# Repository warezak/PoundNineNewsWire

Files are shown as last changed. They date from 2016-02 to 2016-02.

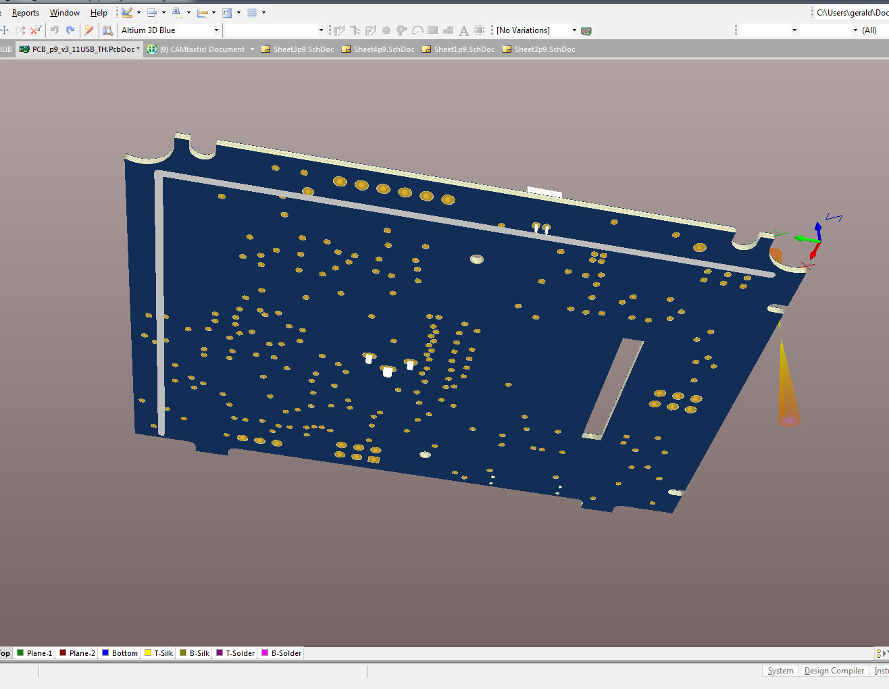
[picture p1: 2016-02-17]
PCB/pcb_p9_v3_view4.jpg

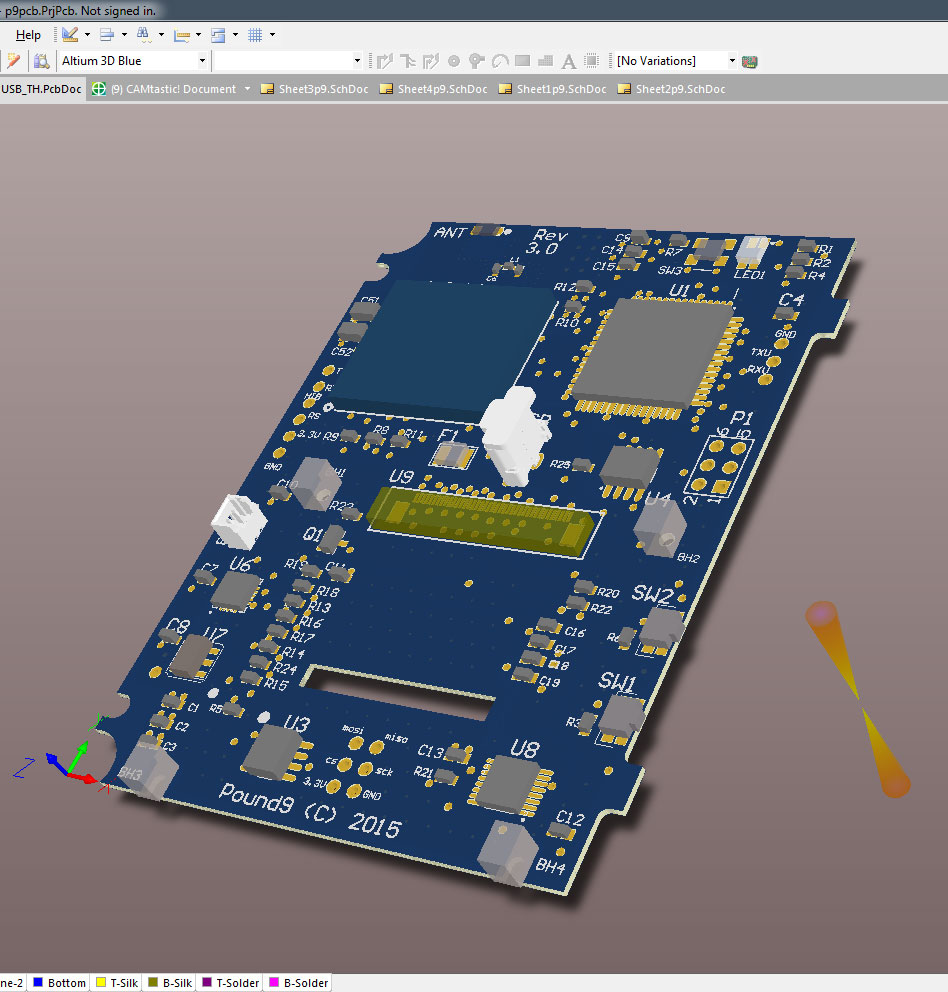
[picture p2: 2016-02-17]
PCB/pcb_p9_v3_view2.jpg

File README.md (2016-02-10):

# PoundNineNewsWire
Source code for #9 Personal News Wire

The Pound Nine Wire is a wifi enabled (TICC3100), battery operated, hardware device with 3.2" touch screen display. The Pound Nine Wire continually streams live headlines from a database of content. Just glance at the device to stay informed while you stay focused on the tasks at hand.

A full description of the product can be view on the project kickstarter page: https://www.kickstarter.com/projects/1547604553/stream-live-news-updates-on-your-personal-wire

The product was not funded and is not be pursued at this time. A lot of work went into the hardware and firmware design which is posted here. Feel free to leverage the source code in your projects. The project uses a Atmel ATxmega256A3U and TICC3100. Schema and gerber files are available in PCB directory. Firmware to connect device to internet and continually retreive content is posted in Firmware folder. ImageLoader is firmware to load image hex files onto SRAM chip. Not elegant, but functional.

There is a companion android app that operates as a news wire, publishing the same content pushed to the standalone hardware. In the mobile app is a customized version of the CC3100 smart config app. 

The 3d model files are available so you can print your own case.

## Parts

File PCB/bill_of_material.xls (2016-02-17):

Manufacturer | Manufacturer Part Number | Supplier | Supplier Part Number | Required Quantity | Reference Designator (Component Location) | Existing Stock Availablity | Order Quantity | Currency | Mike tmp | Mike Ext | Unit Price | Total Price | MOQ | Residual Quantity | Base Part Number
Taiyo Yuden | AH316M245001-T | Digikey | 587-2200-1-ND | 1 | ANT | 0 | 1 | USD | 0.585 | 0.585 | 1.95 | 1.95 | 1 | 0 | AH316M245001-T
Murata | GJM1555C1H1R0CB01D | Digikey | 490-3083-1-ND | 1 | C6 | 0 | 1 | USD | 0.12 | 0.12 | 0.12 | 0.12 | 1 | 0 | CAP CER 1PF 50V NP0 0402
Vishay / Vitramon | VJ0603Y104JXQPW1BC | Mouser | 77-VJ0603Y104JXQPBC | 9 | C1, C4, C12, C13, C14, C16, C17, C18, C19 | 0 | 9 | USD | 0.1 | 0.9 | 0.1 | 0.5 | 1 | 0 | VJ0603Y104JXQPW1BC
TDK | C1005X5R1C105K050BC | Digikey | 445-4978-1-ND | 3 | C11,C2,C15 | 0 | 3 | USD | 0.016 | 0.048 | 0.12 | 0.36 | 1 | 0 | X5R-1u-16V-20%-0603
AVX | F930J107KAA | Digikey | 478-8152-1-ND | 2 | C51,C52 | 0 | 2 | USD | 0.85 | 1.7 | 0.89 | 1.78 | 1 | 0 | F930J107KAA
Molex | 530470210 | Mouser | 538-53047-0210 | 1 | P3 | 0 | 1 | USD | 0.11587 | 0.11587 | 0.35 | 0.35 | 1 | 0 | 530470210
Molex | 105133-0011 | Mouser | 538-105133-0011 | 1 | P2 | 0 | 1 | USD | 1.06 | 1.06 | 1.11 | 1.11 | 1 | 0 | 105133-0011
BUYDISPLAY | ER-CON40HT-1 | BUYDISPLAY | ER-CON40HT-1 | 1 | U9 | 0 | 1 | USD | 0.17 | 0.17 | 0.17 | 0.17 | 1 | 0 | ER-CON40HT-1
Bourns | MF-USMF110-2 | Digikey | MF-USMF110-2CT-ND | 1 | F1 | 0 | 1 | USD | 0.181 | 0.181 | 0.29 | 0.29 | 1 | 0 | MF-USMF110-2
Microchip Technology | 23A256-I/SN | Mouser | 579-23A256-I/SN | 1 | U4 | 0 | 1 | USD | 1.04 | 1.04 | 1.28 | 1.28 | 1 | 0 | 23A256-I/SN
XPT | XPT-2046 | ALIBABA | XPT-2046 | 1 | U8 | 0 | 1 | USD | 0.2 | 0.2 | 0.2 | 0.2 | 1 | 0 | XPT-2046
Adesto Technologies | AT45DB161E-SSHF-B | Digikey | 1265-1058-ND | 1 | U3 | 0 | 1 | USD | 1.87 | 1.87 | 2.15 | 2.15 | 1 | 0 | AT45DB161E-SSHF-B
Atmel | ATXMEGA256A3U-AU | Digikey | ATXMEGA256A3U-AU-ND | 1 | U1 | 0 | 1 | USD | 6.169 | 6.169 | 7.26 | 7.26 | 1 | 0 | ATXMEGA256A3U-AU
TI (Texas Instruments) | CC3100MODR11MAMOB | Mouser | 595-3100MODR11MAMOBR | 1 | CC3100M | 0 | 1 | USD | 21.95 | 21.95 | 21.95 | 21.95 | 1 | 0 | CC3100MODR11MAMOB
Microchip Technology | MCP73871-2CCI/ML | Digikey | MCP73871-2CCI/ML-ND | 1 | U6 | 0 | 1 | USD | 1.67 | 1.67 | 1.79 | 1.79 | 1 | 0 | MCP73871-2CCI/ML
On Semiconductor | NCP694D33HT1G | Digikey | NCP694D33HT1GOSCT-ND | 1 | U7 | 0 | 1 | USD | 1.52 | 1.52 | 1.52 | 1.52 | 1 | 0 | NCP694D33HT1G
Taiyo Yuden | HK10053N6S-T | Digikey | 587-1508-1-ND | 1 | L1 | 0 | 1 | USD | 0.012 | 0.012 | 0.1 | 0.1 | 1 | 0 | FIXED IND 3.6NH 500MA 0402
Visual Communications Company (VCC) | VAOL-S1513RGB | Mouser | 593-VAOL-S1513RGB | 1 | LED1 | 0 | 1 | USD | 0.663 | 0.663 | 1.69 | 1.69 | 1 | 0 | VAOL-S1513RGB
Yageo | RC0603FR-071M5L | Digikey | 311-1.50MHRCT-ND | 1 | R18 | 0 | 1 | USD | 0.048 | 0.048 | 0.09 | 0.09 | 1 | 0 | 1.5M--100mW-1%-0603
Yageo | RC0603FR-07100KL | Mouser | 603-RC0603FR-07100KL | 2 | R11,R16 | 0 | 2 | USD | 0.002 | 0.004 | 0.1 | 0.2 | 1 | 0 | 100K-63mW-5%-0603
Yageo | RC0603FR-0710KL | Mouser | 603-RC0603FR-0710KL | 15 | R3, R5, R6, R7, R8, R9, R10, R12, R13, R14, R15, R20, R22, R24, R25 | 0 | 15 | USD | 0.002 | 0.03 | 0.01 | 0.15 | 1 | 0 | 10K-63mW-5%-0603
Yageo | RC0603FR-071KL | Mouser | 603-RC0603FR-071KL | 3 | R1, R2, R4 | 0 | 3 | USD | 0.002 | 0.006 | 0.1 | 0.3 | 1 | 0 | 1K-63mW-5%-0603
Yageo | RC0603FR-072K49L | Digikey | 311-2.49KHRCT-ND | 2 | R17,R23 | 0 | 2 | USD | 0.002 | 0.004 | 0.1 | 0.2 | 1 | 0 | 2.49K-100mW-1%-0603
Yageo | RC0603FR-07430KL | Digikey | 311-430KHRCT-ND | 1 | R19 | 0 | 1 | USD | 0.1 | 0.1 | 0.1 | 0.1 | 1 | 0 | 430K-100mW-1%-0603
Yageo | RC0603FR-0749K9L | Digikey | 311-49.9KHRCT-ND | 1 | R21 | 0 | 1 | USD | 0.038 | 0.038 | 0.1 | 0.1 | 1 | 0 | 49.9K-100mW-1%-0603
ITT / C&K Components | KMT021NGJLHS | Mouser | 611-KMT021NGJLHS | 1 | SW3 | 0 | 1 | USD | 0.155 | 0.155 | 0.43 | 0.43 | 1 | 0 | KMT021NGJLHS
ITT / C&K Components | PTS840GKPSMTRLFS | Mouser | 611-PTS840GKPSMTR | 2 | SW1,SW2 | 0 | 2 | USD | 0.32 | 0.64 | 0.32 | 0.64 | 1 | 0 | PTS840GKPSMTRLFS
On Semiconductor | MMBT3906LT1G | Digikey | MMBT3906LT1GOSCT-ND | 1 | Q1 | 0 | 1 | USD | 0.031 | 0.031 | 0.11 | 0.11 | 1 | 0 | MMBT3906LT1G
Murata | GRM188R61A106KE69D | Mouser | 81-GRM188R61A106KE9D | 5 | C3,C7,C8,C9,C10 | 0 | 5 | USD |  |  | 0.067 | 0.067
BuyDisplay | ER-TFT032-3.1 + Touch | BuyDisplay | ER-TFT032-3.1 + Touch | 1 |  |  |  |  |  |  |  | 9.32 |  |  | ER-TFT032-3.1 + Touch
Battery | 3.7V T5.8*W39*43mm 800mAh 3.7V lipo | Battery | 3.7V T5.8*W39*43mm 800mAh 3.7V lipo | 1 |  |  |  |  |  |  |  | 1.65

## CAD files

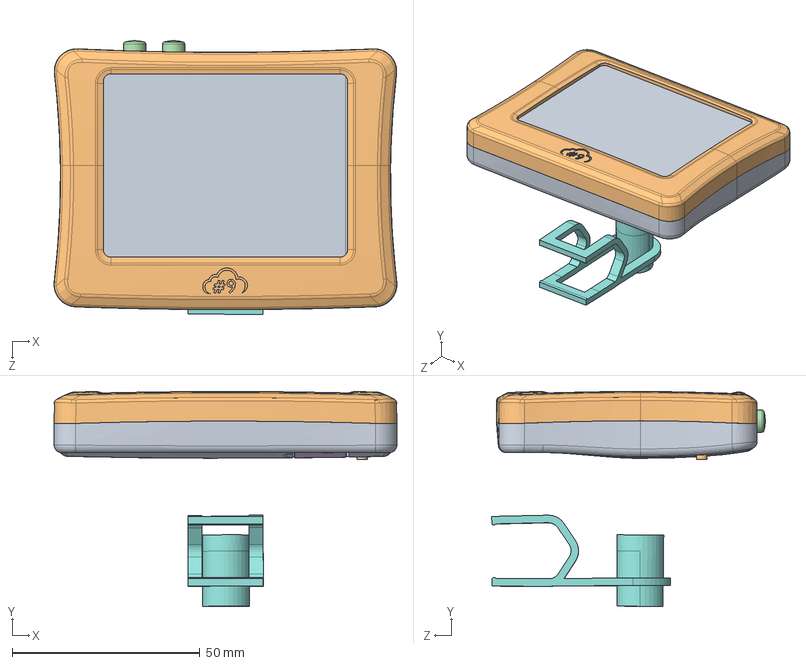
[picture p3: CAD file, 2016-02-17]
3DModel/Solidworks files/Model-221-08-2015.SLDASM
91.3 x 57.3 x 72.8 mm
display21-08-2015
BIVAR LIGHTPIPE PLP2-12521-08-2015
micro-usb21-08-2015
b3u-3100p-b21-08-2015 x 2
Copy of Copy of Wifi-chip^Electronics21-08-2015
3 COLOR LED21-08-2015
Battery-holder21-08-2015
Back21-08-2015
Front-part
battery21-08-2015
Push-button x 2
93365A11021-08-2015 x 4
Kickstand-121-08-2015
pan cross head_ai x 4
91585A01421-08-2015

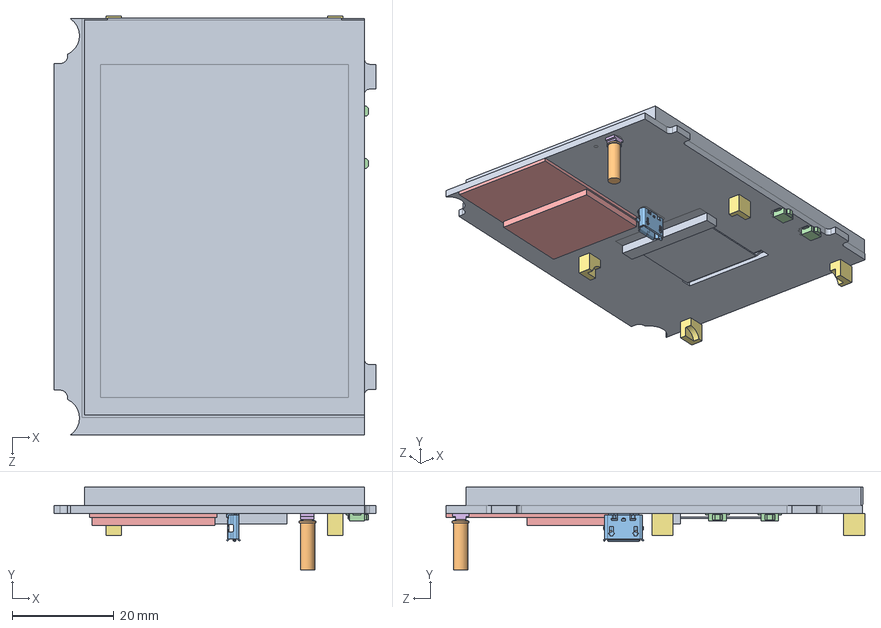
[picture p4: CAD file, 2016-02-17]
3DModel/Solidworks files/Electronics21-08-2015.sldasm
63.2 x 16.3 x 82.3 mm
display21-08-2015
BIVAR LIGHTPIPE PLP2-12521-08-2015
micro-usb21-08-2015
b3u-3100p-b21-08-2015 x 2
Copy of Copy of Wifi-chip^Electronics21-08-2015
3 COLOR LED21-08-2015
Battery-holder21-08-2015

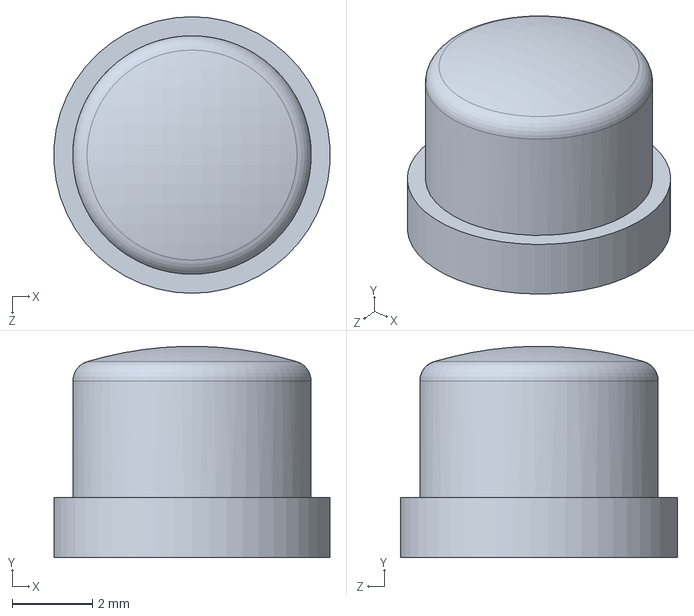
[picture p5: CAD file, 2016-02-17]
3DModel/Solidworks files/Push-button.sldprt
6.89 x 5.27 x 6.90 mm

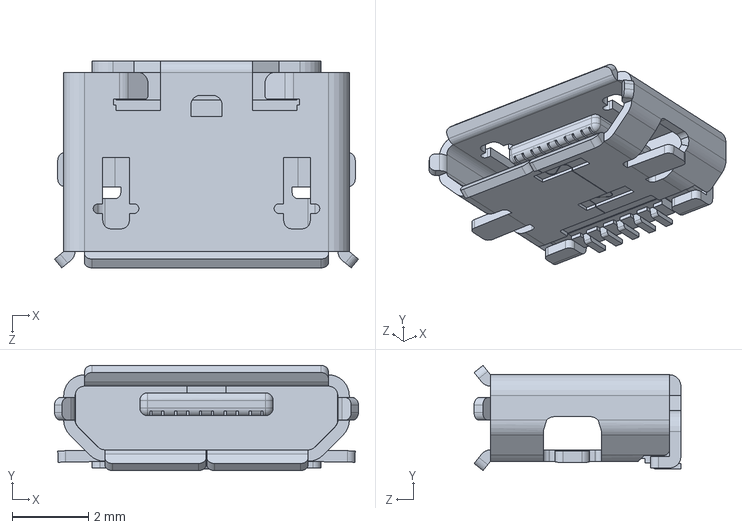
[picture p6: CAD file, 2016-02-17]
3DModel/Solidworks files/micro-usb21-08-2015.SLDPRT
7.98 x 2.76 x 5.43 mm

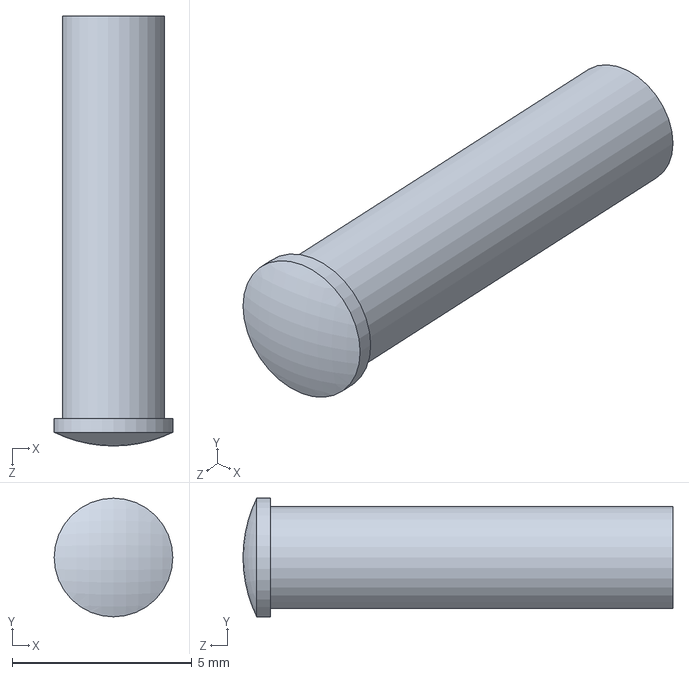
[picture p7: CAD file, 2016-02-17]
3DModel/Solidworks files/BIVAR LIGHTPIPE PLP2-12521-08-2015.sldprt
3.30 x 3.30 x 12.0 mm

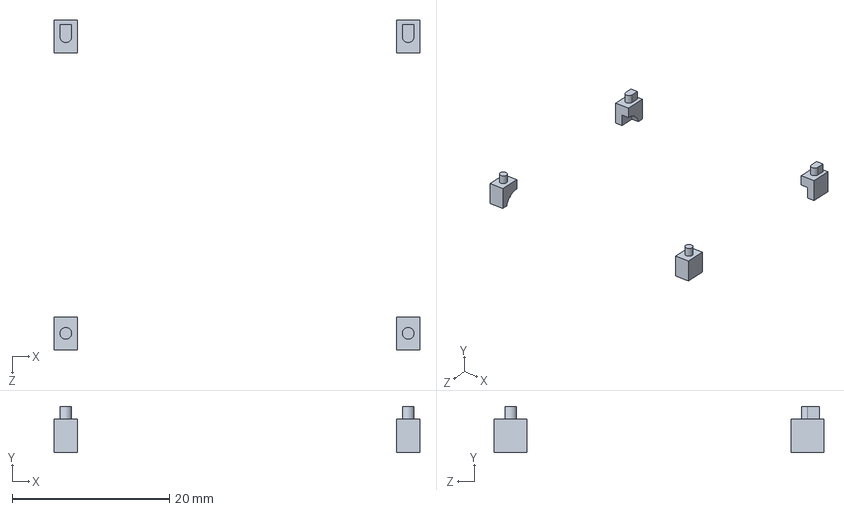
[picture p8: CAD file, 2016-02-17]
3DModel/Solidworks files/Battery-holder21-08-2015.sldprt
46.5 x 5.88 x 41.9 mm

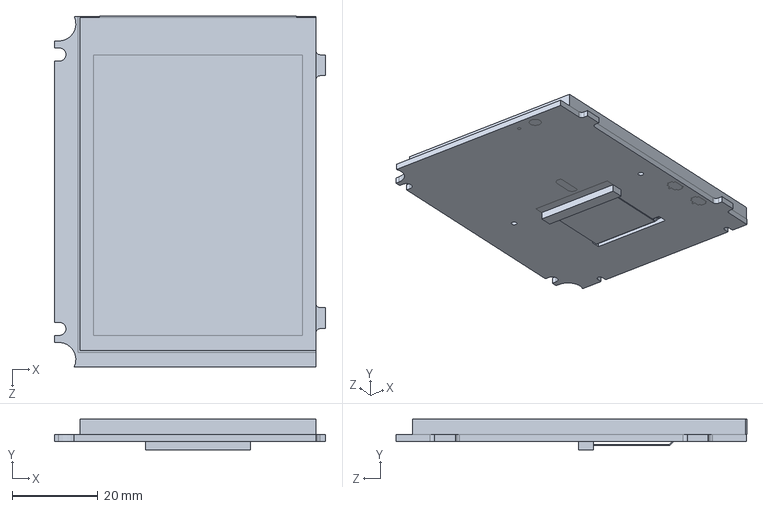
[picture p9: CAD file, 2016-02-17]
3DModel/Solidworks files/display21-08-2015.SLDPRT
63.2 x 7.23 x 81.9 mm

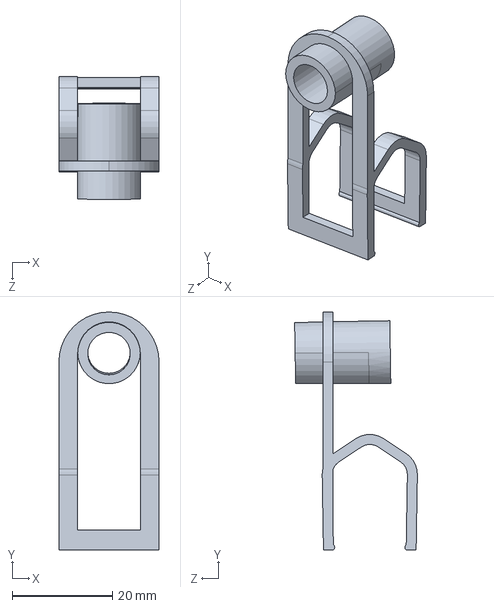
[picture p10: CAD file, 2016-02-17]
3DModel/Solidworks files/Monitor-holder21-08-2015.sldprt
20.0 x 47.5 x 24.5 mm

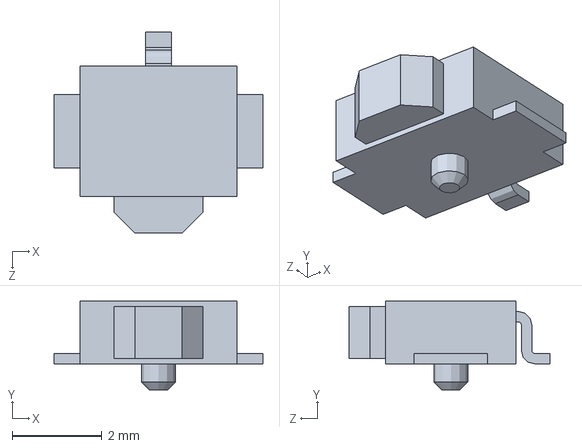
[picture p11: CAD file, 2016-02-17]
3DModel/Solidworks files/b3u-3100p-b21-08-2015.SLDPRT
4.67 x 1.98 x 4.49 mm

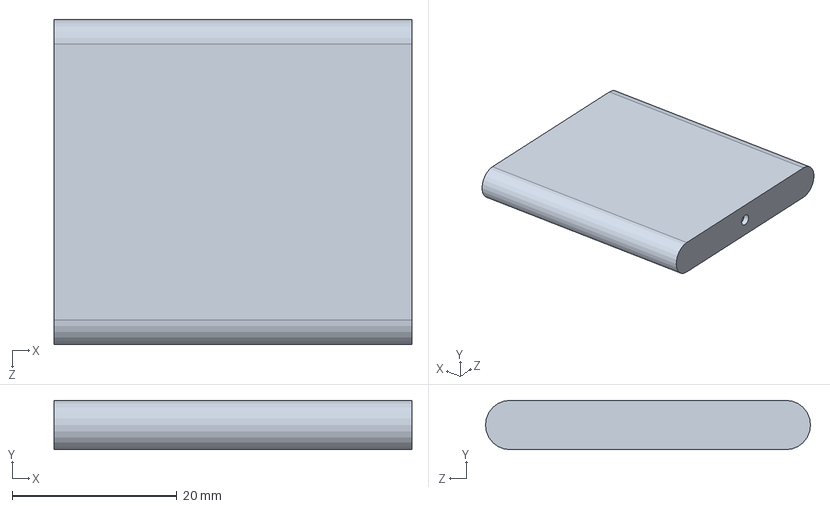
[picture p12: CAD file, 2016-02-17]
3DModel/Solidworks files/battery21-08-2015.SLDPRT
43.5 x 6.00 x 39.5 mm

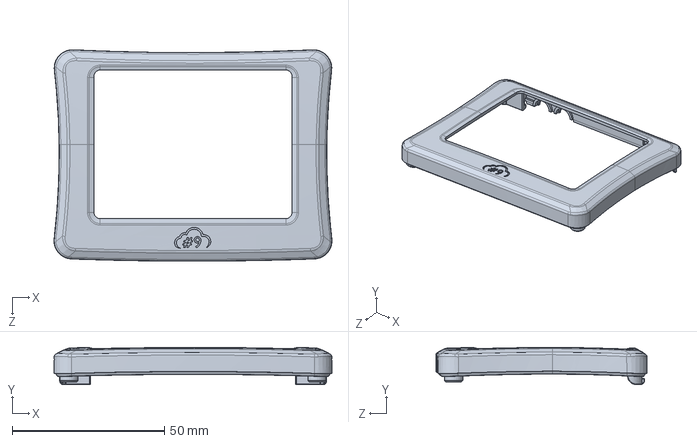
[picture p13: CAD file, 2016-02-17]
3DModel/Solidworks files/Front-part.sldprt
91.3 x 12.2 x 69.4 mm

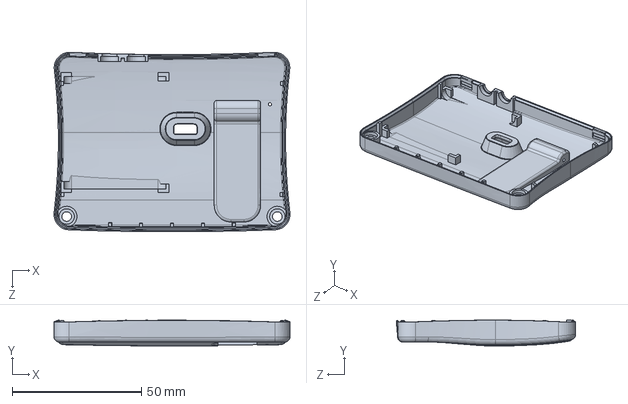
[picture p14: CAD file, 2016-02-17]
3DModel/Solidworks files/Back21-08-2015.sldprt
91.3 x 10.1 x 69.4 mm

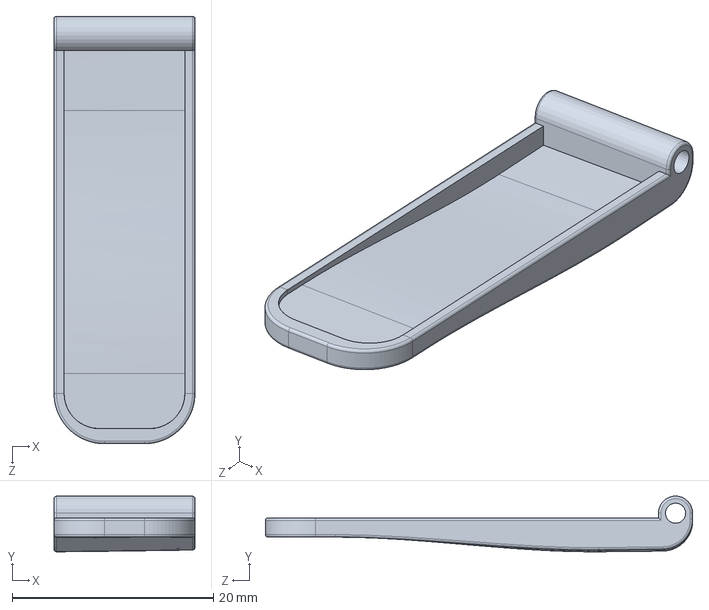
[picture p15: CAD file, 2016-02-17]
3DModel/Solidworks files/Kickstand-121-08-2015.SLDPRT
14.0 x 5.53 x 42.4 mm

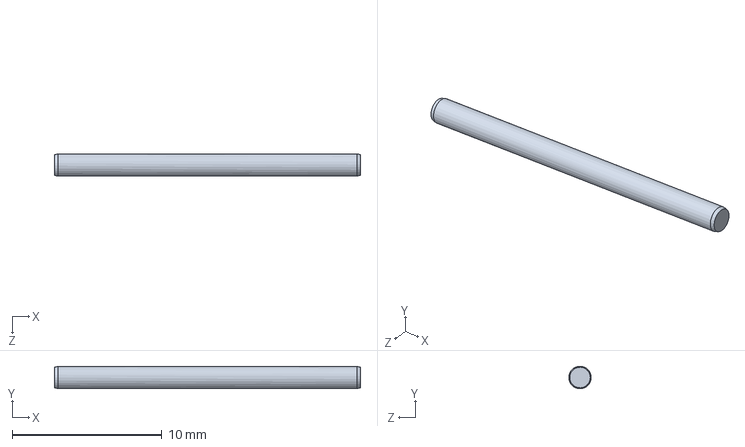
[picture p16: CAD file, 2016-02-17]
3DModel/Solidworks files/91585A01421-08-2015.SLDPRT
20.5 x 1.50 x 1.50 mm

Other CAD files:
3DModel/Solidworks files/3 COLOR LED21-08-2015.sldprt
3DModel/Solidworks files/93365A11021-08-2015.SLDPRT
3DModel/STL files/Push-button.STL

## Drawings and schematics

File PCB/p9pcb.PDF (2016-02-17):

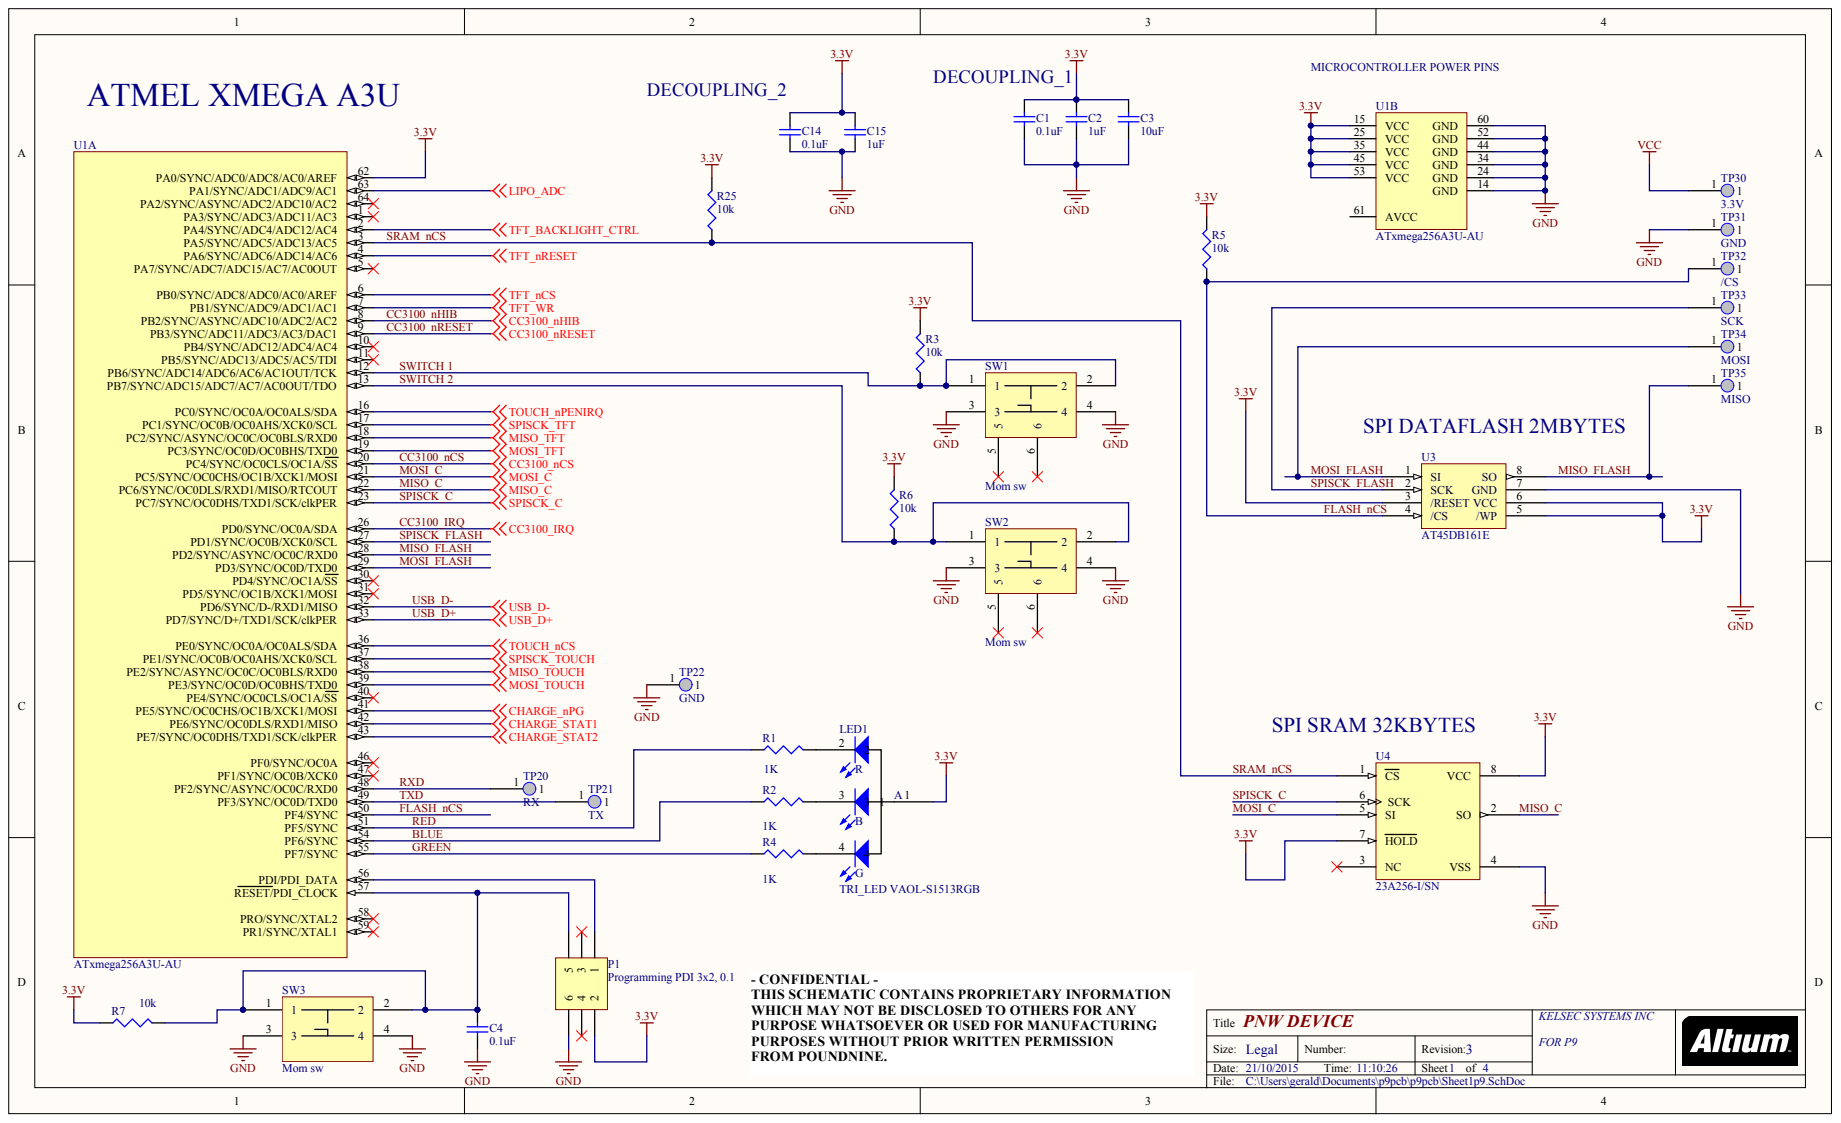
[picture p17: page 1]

2 5 | 5 2
3 5 | 4 4
4 5 | 3 4
5 3 | 2 4

SPISCK_FL

3 | SCK GN D /RESE T VCC /CS /W P | 6

KELSEC SYSTEMS INC FOR P9

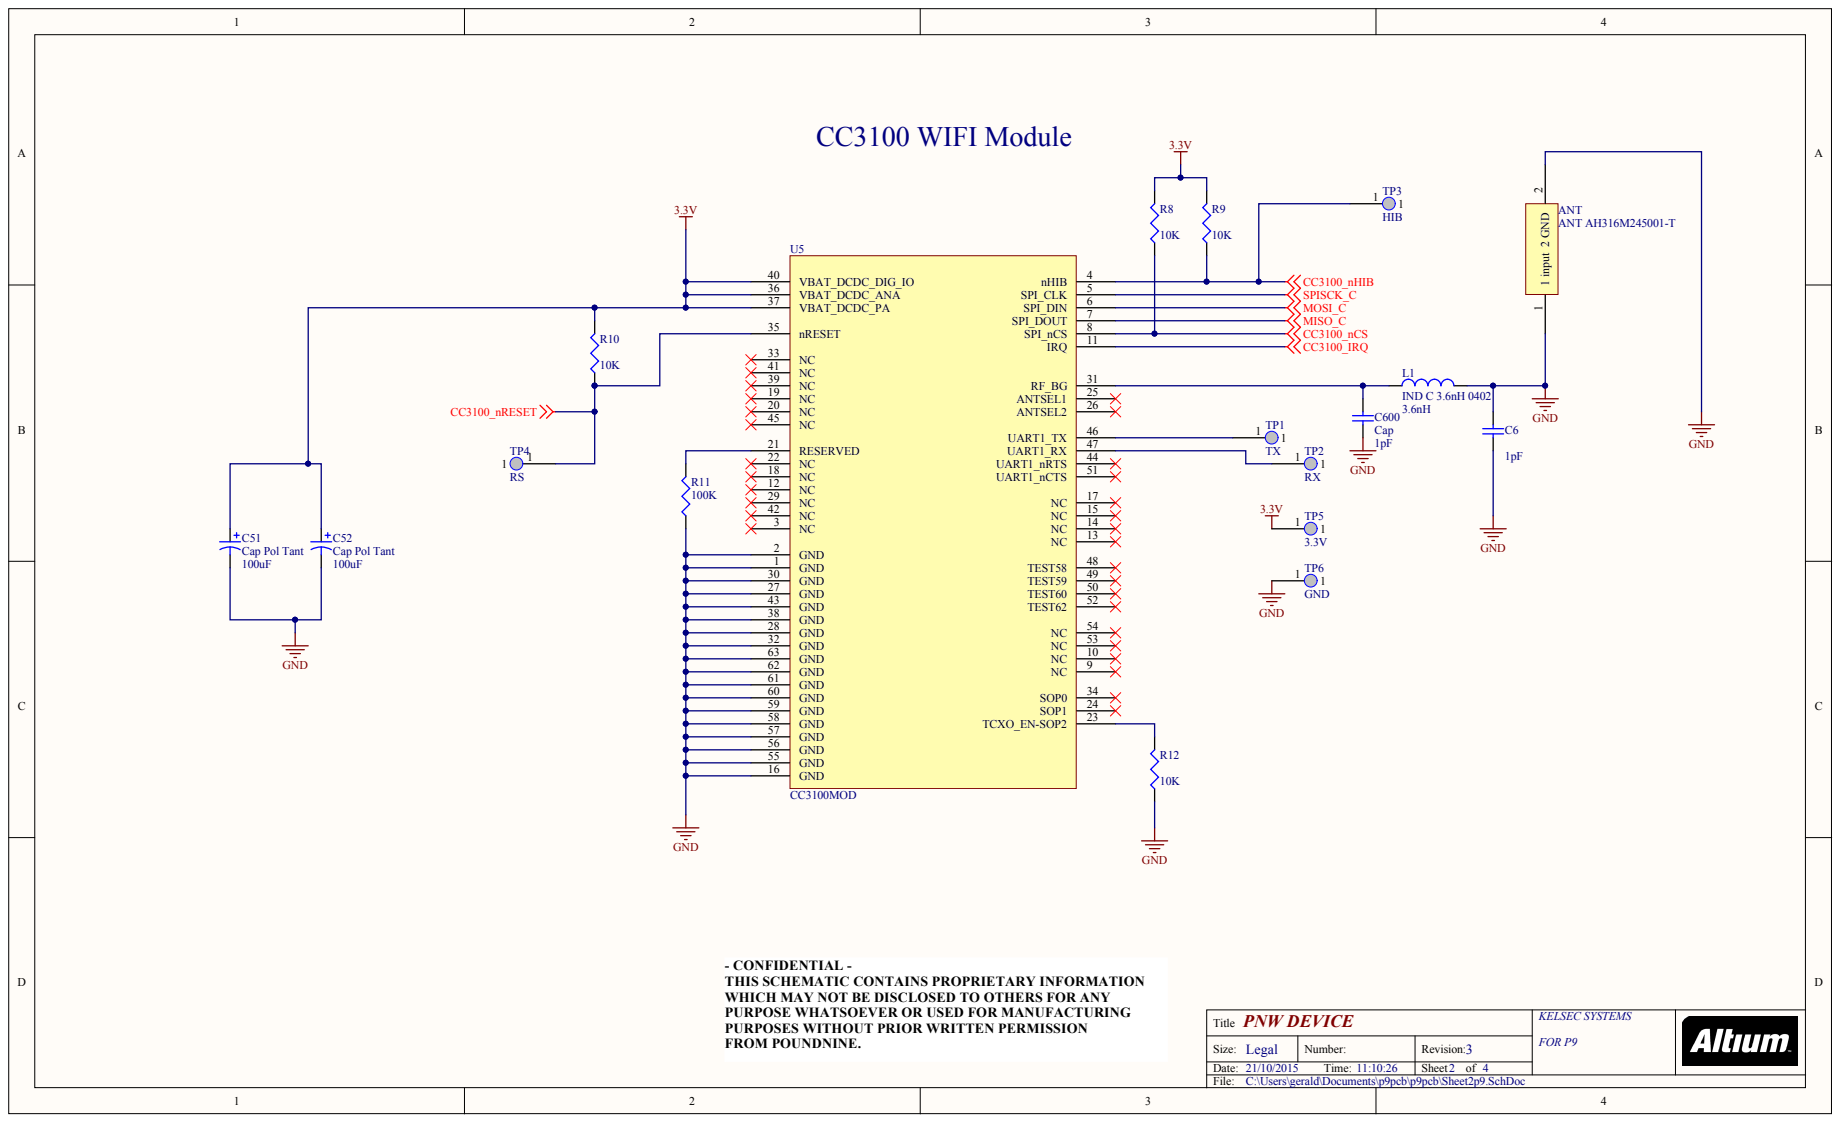
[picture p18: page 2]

3 6
3 7

3 0 | 4 9
2 7 | 5 0
4 3 | 5 2
3 8 | 5 4

3 2 | 5 3
6 3 | 1 0
6 2 | 9
6 1 | 3 4

5 9 | 2 4
5 8 | 2 3

T i t l e PNW DEVICE | KELSEC SYSTEMS FOR P9

Size: Legal | N umber: | Rev i s i o n : 3
Date: 2 1 / 1 0 / 2 0 1 5 T ime: 1 1 : 1 0 : 2 6 | | Sheet 2 o f 4
Fi le: C: \U sers \ geral d\ D ocumen t s \p 9 pcb \p 9 pcb \Sheet 2 p 9.Sch D o c

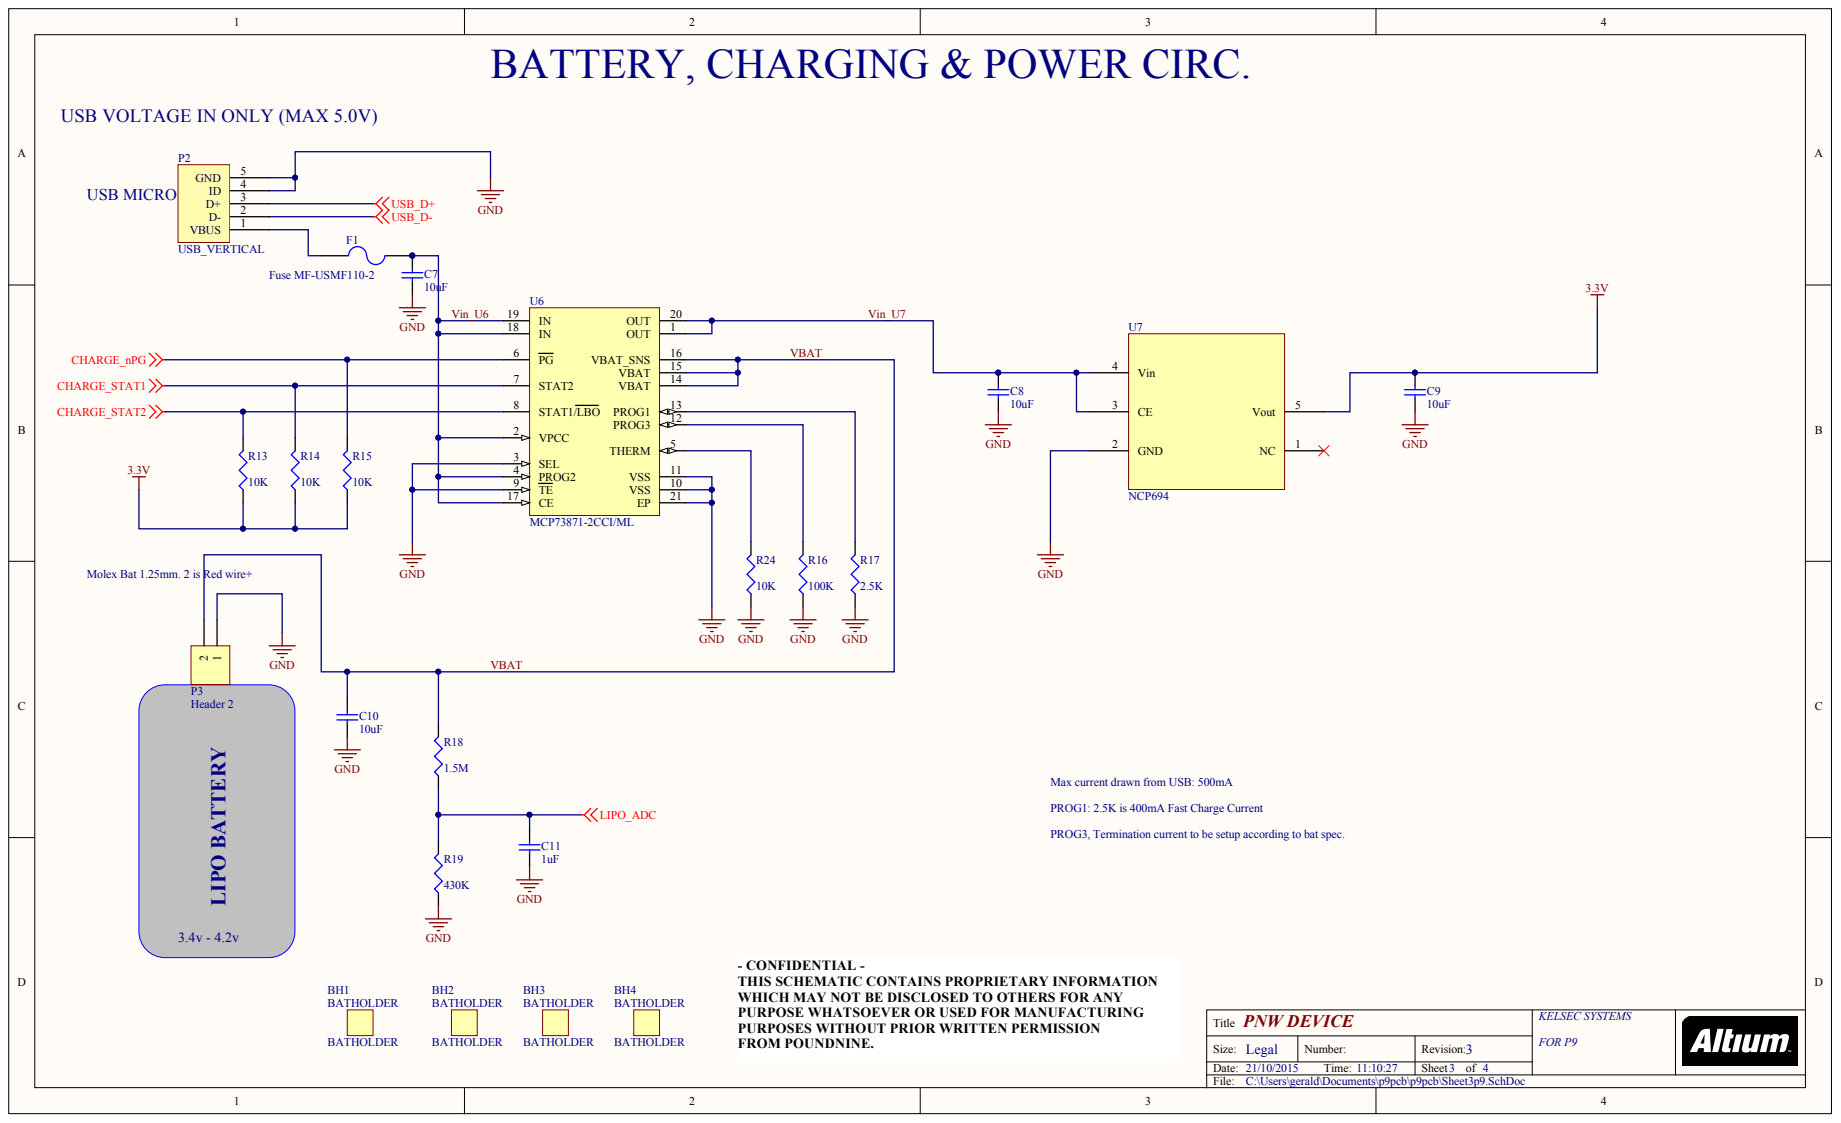
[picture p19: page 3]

BATTERY, CHARGING & POWER CIRC. GND

9 | | 1 0
1 7 | | 2 1

T i t l e PNW DEVICE | KELSEC SYSTEMS FOR P9

Size: Legal | N umber: | Rev i s i o n : 3
Date: 2 1 / 1 0 / 2 0 1 5 T ime: 1 1 : 1 0 : 2 7 | | Sheet 3 o f 4
Fi le: C: \U sers \ geral d\ D ocumen t s \p 9 pcb \p 9 pcb \Sheet 3 p 9.Sch D o c

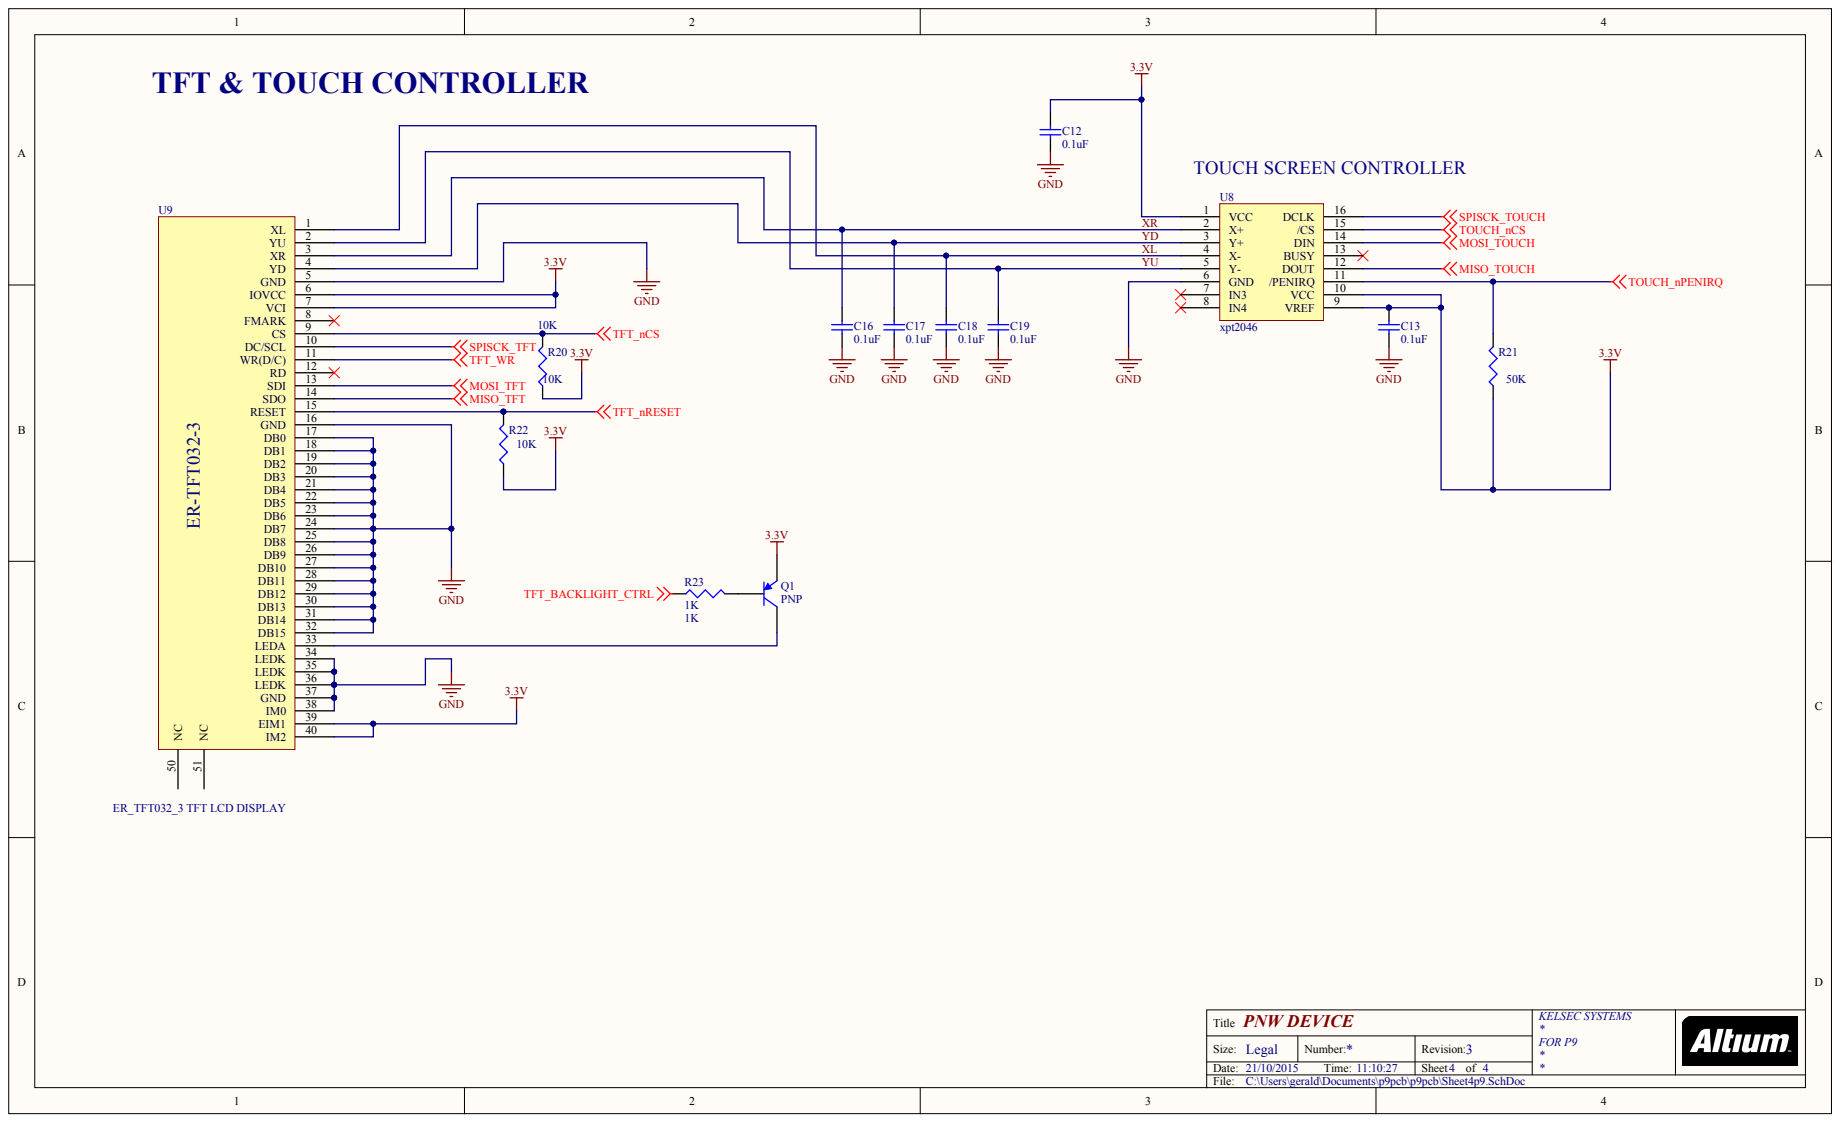
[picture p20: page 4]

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
T i t l e | KELSEC SYSTEMS *FOR P9 * *

Size: Legal | N umber: | Rev i s i o n : 3
Date: 2 1 / 1 0 / 2 0 1 5 T ime: 1 1 : 1 0 : 2 7 | | Sheet 4 o f 4
Fi le: C: \U sers \ geral d\ D ocumen t s \p 9 pcb \p 9 pcb \Sheet 4 p 9.Sch D o c

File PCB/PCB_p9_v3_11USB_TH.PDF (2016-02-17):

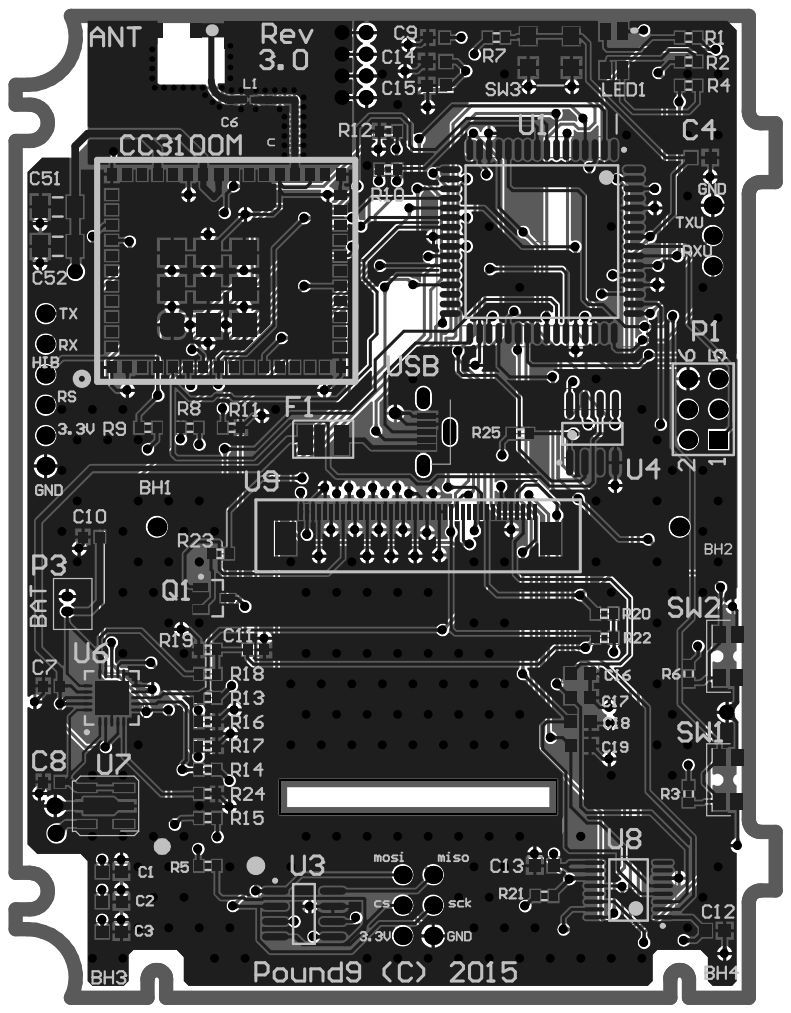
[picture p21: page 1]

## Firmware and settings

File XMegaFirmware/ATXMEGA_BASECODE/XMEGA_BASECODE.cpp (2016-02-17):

/**
 * 
 * XMEGA_BASECODE.cpp
 /*
 */

//Atmel ASF DOES NOT compile under C++ (as of Atmel Studio 6.2) Must use C compiler
extern "C" {
#include "src/asf.h"	
	};
#include <avr/io.h>
#include <util/delay.h>
#include <avr/pgmspace.h>
#include <string.h>

//cc3100 Adafruit for Arduino - modified by gp for atxmega
#include <Adafruit_CC3100.h>
#include "spi_wrapper.h" 
#include <string.h>

#include "cli_uart_wrapper.h" // Debug Only
#include "screens.h" // uses in screen loading
#include "ui_objects.h" // uses in touch test
#include "SRAM23K256.h" //uses for ram
#include "BaseCodeSub.h"

typedef char CHAR; 
//function prototype
//arduino compatibility
void setup();
void loop();
void wifi_test();
void setUp32MhzInternalOsc();
void setColor(int,int,int);
void clearStr(char*);
void addChar (char ch, char* str);
boolean matchTag (char* searchTag);
//gerald
char* appendCharToCharArray(char*, char);

//cc31000
uint16_t checkFirmwareVersion();
void displayMACAddress();
void listSSIDResults();

bool connect_accesspoint();
uint8_t getConfigModeFromNVM(uint8_t); //argument is NVM address location
boolean process_xml(int);
boolean process_restart();
int get_server_content();
 
//XMEGA SPECIFIC NVM
#define EEPROM_SSID_ADR			5
#define EEPROM_PWD_ADR			45
#define	EEPROM_CONFIGMODE_ADR	0
// config mode serial (3)

//cc3100
//Activating CC3100
#define SWITCH_POWER_CC3100		29
#define ADAFRUIT_CC3100_IRQ		24  // xmega gpio0, PD0
#define ADAFRUIT_CC3100_VBAT	25  //xmega pin25, gpio1
#define ADAFRUIT_CC3100_CS		20  //xmega SS pin port C
Adafruit_CC3100 cc3100			= Adafruit_CC3100(ADAFRUIT_CC3100_CS, ADAFRUIT_CC3100_IRQ, ADAFRUIT_CC3100_VBAT, SPI_CLOCK_DIVIDER);

// Security can be WLAN_SEC_UNSEC, WLAN_SEC_WEP, WLAN_SEC_WPA or WLAN_SEC_WPA2
#define WLAN_SECURITY			SL_SEC_TYPE_WPA_WPA2
#define IDLE_TIMEOUT_MS			15000
#define DEVICE_NAME				"CC3100"
#define AP_ATTEMPTS				1 //how many attempts at connecting to access point
#define DHCP_TIMEOUT			60000 //in ms.

//OLED
#define __AVR_XMEGA__
#define OLED_POWER_12V			4 //pa4, for gracefully powering up the 12V on the Oled.
#define RESET_OLED				27
#define CS_OLED					28
#define A0_OLED					26

//LEDs DEFINITION:
#define LED_PA0_R				0
#define LED_PA1_B				1
#define LED_PA2_G				2

// Config Button
#define BUTTON_PIN				IOPORT_CREATE_PIN(PORTF,1) // SW1 on xplained board xmega256a3bu


// set device serial id YYMM, Software Version (4), id (8)
#define P9_SERIALID          "set serial" 
#define WEBSITE              "set url"

//global variables & flag
uint32_t       ip;
char           fail        = 'N';
char           format[3];
char           loop_speed[3];
int            iEnd        = 0;
const unsigned long dhcpTimeout     = 60L * 1000L; // Max time to wait for address from DHCP
long previousMillis = 0;        // will store last time LED was updated
unsigned int iConnectFail = 0;
unsigned int i;


//Required pointer global variables for passing router credentials between functions
char* ssid1;
char* pwd1;	  

#define YOUR_SSID "set ssid" // only when not using smart config or ap provisioning
#define PASSWORD "set password"

//#define YOUR_SSID "GalaxyS5"
//#define PASSWORD "123456789"

//for xml parsing
#define       MAX_STRING_LEN           258
char          tagStr[10]               = "";
char          dataStr[MAX_STRING_LEN]  = "";
char          tmpStr[MAX_STRING_LEN]   = "";
char          endTag[3]                = {'<', '/', '\0'};
unsigned int  len;

// Flags to differentiate XML tags from document elements (ie. data)
boolean tagFlag = false;
boolean dataFlag = false;


const char TextA[] PROGMEM = "Hello from #9\r\n";
const char TextB[] PROGMEM = "Please enter a configuration mode  ...\r\n";
const char TextC[] PROGMEM = "Not able to get IP address for poundnine.com\r\n";
const char TextD[] PROGMEM = "PoundNine.com IP: ";
const char TextE[] PROGMEM = "Reset Connection, >3 failed attempts\r\n";
const char TextF[] PROGMEM = "Connection failed\r\n";
const char TextG[] PROGMEM = "Format:";
const char TextH[] PROGMEM = "Speed: ";
const char TextI[] PROGMEM = "Header: ";
const char TextJ[] PROGMEM = "Line: ";
const char TextK[] PROGMEM = "Time Since: ";
const char TextL[] PROGMEM = "ClearBuffers\r\n";
const char TextM[] PROGMEM = "End XML Result\r\n";
const char TextO[] PROGMEM = "Unable to retrieve the firmware version!\r\n";
const char TextP[] PROGMEM = "Firmware V. :";
const char TextQ[] PROGMEM = "Unable to retrieve MAC Address!\r\n";
const char TextR[] PROGMEM = "MAC Address : not printed but there\r\n";
const char TextS[] PROGMEM = "SSID scan failed!\r\n";
const char TextT[] PROGMEM = "Networks found: ";
const char TextU[] PROGMEM = "================================================\r\n";
const char TextV[] PROGMEM = "SSID Name:";
const char TextW[] PROGMEM = "Connecting to Access Point:";
const char TextX[] PROGMEM = ".";
const char TextY[] PROGMEM = "Reconnecting with SmartConfig ...\r\n";
const char TextZ[] PROGMEM = "Initializing the CC3100 ...\r\n";
const char TextA1[] PROGMEM = "SmartConfig Reconnect Failed";
const char TextB1[] PROGMEM = "Reconnected ...\r\n";
const char TextC1[] PROGMEM = "Connecting with USBConfig ...\r\n";
const char TextD1[] PROGMEM = "SmartConfig failed, try again";
const char TextE1[] PROGMEM = "Unable to initialize the CC3100";
const char TextF1[] PROGMEM = "Deleting old connection profiles ...\r\n";
const char TextG1[] PROGMEM = "Failed deleting old profiles";
const char TextH1[] PROGMEM = "Please enter a configuration mode  ...\r\n";
const char TextI1[] PROGMEM = "Unable to retrieve the IP Address!\r\n";
const char TextJ1[] PROGMEM = "IP Addr: ";
const char TextK1[] PROGMEM = "Netmask: ";
const char TextL1[] PROGMEM = "Gateway: ";
const char TextM1[] PROGMEM = "DHCPsrv: ";
const char TextN1[] PROGMEM = "DNSserv: ";
const char TextO1[] PROGMEM = "Connect to AP failed";
const char TextP1[] PROGMEM = "Process result set";
const char TextQ1[] PROGMEM = "Connection Parameters Saved ...\r\n";
const char TextR1[] PROGMEM = "Requesting DHCP ...\r\n";
const char TextS1[] PROGMEM = "DHCP failed, try again\r\n";
const char TextT1[] PROGMEM = "Successfully connected to Access Point\r\n";
const char TextU1[] PROGMEM = "Internet Setup completed \r\n";

const char TextN[] PROGMEM = "\r\n";

// To Do bhautik,http request
const char Text1[] PROGMEM = "GET ";
const char Text2[] PROGMEM = "/wp-content/themes/jupiter/p9/datafeed_ajax.php?mode=xml"; //set url to get xml content
const char Text3[] PROGMEM = "&id=";
const char Text3A[] PROGMEM = "&x=";
const char Text4[] PROGMEM = " HTTP/1.1\r\n";
const char Text5[] PROGMEM = "Host: ";
const char Text6[] PROGMEM = "\r\n";



//spi SRAM microchips
#define MAXSPIRAM	11000 //max is 32000 for 256kbits chip
char wValue;
char rValue;
uint16_t address = 0; //up to 65536
uint16_t indexer = 0;

#define SS_PIN 05 //pin1 on xmega128a4u, PA5

byte clock = 0;
extern int8_t g_Wlan_SSID[];
extern int8_t g_Wlan_Security_Key[];
extern bool bConnectionError;

int		cycles = 0;
int		last_char = 0;
int		h; //total num chars in response

// Extern from BaseCodeSub.h
extern ScreenStateInfo_e gxScreenStatePrevious;
extern CredentialInfo_t gxCredentialInfo;
//extern ContentInfo_t gxContentInfo;
extern ScreenInfo_t gxScreenInfo;

// Other
boolean bRestartLoop = false;
static char FilterInURL[20] = "";
// Implemented In last
void vInitScreen(void);
void vInitCredentialProcess(void);
void vFlipScreen180(void);
struct ui_news news, news1;  // to hold processed xml for display
// Declared in screen.h,called from screen.c
void go_home(void)
{
	
}
void vFrom_Screen_FilterSetting(void)
{
	gxScreenInfo.bFilterScreenEnabled = true;
}
void vFilterProcess(char* filterName)
{
	unregister_all_touch_objects();
	gxScreenInfo.bLoadingContentProgressBAR = true;
	bRestartLoop = true;
	gxScreenInfo.bFilterScreenEnabled = false;
	
	if(strcmp("Settings",filterName) == 0) // for this filter stops filter displaying process
	{
		gxScreenInfo.xScreenState = SCREEN_STATE_SETTINGS;
		vUpdateScreen();
		gxCredentialInfo.xCredentialProcessInfo = CREDENTIAL_PROCESS_UNKNOWN;
		gxCredentialInfo.bCredentialProcessDone = false;
		gxCredentialInfo.bSettingCredentialButtonPressed = true;
		CLI_Write("\r\nSelected Filter Is :- Settings ");
	}
	else
	{
		clearStr(FilterInURL);
		strcpy(FilterInURL,filterName);
		CLI_Write("\r\nSelected Filter Is :- ");
		CLI_Write(FilterInURL);
	}
}
void set_email_status(int email_disp_status)
{
	
}
void reset_idle_timer(void)
{
	
}
void click_on_credential_type(uint8_t tuReceivedCredentialProcessType)
{
	gxCredentialInfo.bSettingCredentialButtonPressed = true;
	gxCredentialInfo.bCredentialProcessDone = false;
	switch(tuReceivedCredentialProcessType)
	{
		case CREDENTIAL_PROCESS_SMARTCONFIG:
			gxCredentialInfo.xCredentialProcessInfo = CREDENTIAL_PROCESS_SMARTCONFIG;
			break;
			
		case CREDENTIAL_PROCESS_PROVISIONING_AP:
			gxCredentialInfo.xCredentialProcessInfo = CREDENTIAL_PROCESS_PROVISIONING_AP;
			break;
			
		default:
			break;
	}
}



void setup(void) {
	
  	 sysclk_init(); //Init clock compatible with USB
	 //setUp32MhzInternalOsc(); //USB will not work if enabled because of timing issues.
	 vInitClkBoard(); //board_init(); // TO Do Bhautik,Right now Initilize Device(cc3100) also with it
	 delay_init(sysclk_get_cpu_hz());
	 vInitScreen();
	 CLI_Configure(); // To Do Bhautik,Debug Purpose Only
	 // Initialize interrupt vector table support.
	irq_initialize_vectors();

	// Enable interrupts
	cpu_irq_enable();

	/* Call a local utility routine to initialize C-Library Standard I/O over
	 * a USB CDC protocol. Tunable parameters in a conf_usb.h file must be
	 * supplied to configure the USB device correctly.
	 */

	//Initialize delay within system clocking for accurate timing
	
	//Initialize real time clock timing for milliseconds timing results. from internal 32khz clocking
	rtc_init();
	
	InitSRAM();	
	
	ioport_configure_pin(SS_PIN, IOPORT_DIR_OUTPUT); // to do Bhautik,now we are using asf module to configure pins
		
    ioport_configure_pin(OLED_POWER_12V, IOPORT_DIR_OUTPUT | IOPORT_PIN_LEVEL_LOW); // to do Bhautik,now we are using asf module to configure pins

   	ioport_set_pin_low(RESET_OLED);    // turn the OLED off by making the voltage LOW//to do Bhautik,now we are using asf module to configure pins
	delay_ms(100);               //
	ioport_set_pin_high(RESET_OLED);   // turn the OLED on (HIGH is the voltage level)//to do Bhautik,now we are using asf module to configure pins
	  
	//wifi start
	ioport_configure_pin(SWITCH_POWER_CC3100, IOPORT_DIR_OUTPUT);
	ioport_pin_is_low(SWITCH_POWER_CC3100);
	delay_ms(1000); //LET THE CC3100 POWER UP
	
	setColor(0, 0, 0);  // white
	strcpy(FilterInURL,"Latest"); // Init Filter Text
	vInitCredentialProcess();
}
	

void vGetPoundNineIP(void)
{
	
	// get website.com IP address
	while (ip == 0) {
		setColor(255,0,255); //green
		//	delay(100);
		if (!cc3100.getHostByName(WEBSITE, &ip)) {
			setColor(0, 255, 255);  // red
		}
		setColor(0, 0, 0);  // white
	}
	
	cc3100.printIPdotsRev(ip);
	
	  
	
		 
}


void loop(void) {
	
	uint32_t currentMillis = rtc_get_time();
	char buffer [40];
	
	// either first load or reached end of xml response, time to load from server
	if ((h == 0) || (last_char >= MAXSPIRAM) || (bRestartLoop == true) ) {
		
		last_char = 0;
		
		//Print number of time though loop
		cycles++;
		CLI_Write("\r\n");
		sprintf(buffer,"Millis # %ld\r\n",currentMillis);
		CLI_Write("\r\n");
		CLI_Write(buffer);
		sprintf(buffer,"Iteration # %d\r\n",cycles);
		CLI_Write("\r\n");
		CLI_Write(buffer);
		CLI_Write("----------------------------------------------------------------\r\n");
		
		previousMillis = currentMillis;
		setColor(0, 0, 255);  // yellow
				
		// 3 connection failures, reset and try again
		if (iConnectFail > 3) {
				if (process_restart()) {
					CLI_Write("restart sucess");
					setColor(255, 0, 255);  // green
					} else {
					CLI_Write("restart fail");
					setColor(0, 255, 255);  // red
					while(1);
				}
		} 
		
		h = get_server_content();
		// need to figure out how to pass failure of get_server_content
		
		//Clean up SPI SRam memory by filling with 0 - for debug but may not be necessary for production
		for(indexer=0;indexer<MAXSPIRAM;indexer++){
			//SpiRam.write_byte(indexer,0);
		}
		bRestartLoop = false;
		gxScreenInfo.bDoNOtWaitGoForDisplayingAfterEveryIteration = true;
	}
	else
	{
		// print updates every 8 seconds
		if ((gxScreenInfo.iContentScreenDisplayTime >= DISPLAY_CONTENT_TIMEOUT) || (gxScreenInfo.bDoNOtWaitGoForDisplayingAfterEveryIteration == true))
		{
			gxScreenInfo.bDoNOtWaitGoForDisplayingAfterEveryIteration = false;
			if(gxScreenInfo.bLoadingContentProgressBAR == true)
			{
				vScreenLoadingBar(8);
				vScreenLoadingBar(9);
				gxScreenInfo.bLoadingContentProgressBAR = false;
			}
			if(process_xml(h))
			{
				register_filter_callback();
				CLI_Write("------\r\n");
				gxScreenInfo.iContentScreenDisplayTime = 0;
			}
		} 
		else
		{
			if(gxScreenInfo.bFilterScreenEnabled == false)
			{
				_delay_ms(1);
				gxScreenInfo.iContentScreenDisplayTime++;
			}
		}
	
	}
			
}  // end loop


/**************************************************************************/
/*!
    @brief  Tries to read the CC3100's internal firmware patch ID
*/
/**************************************************************************/
uint16_t checkFirmwareVersion(void) {
  
  uint8_t major, minor;
  uint16_t version;
  
  if(!cc3100.getFirmwareVersion(&major, &minor))
  {
    printf_P(TextO);
	//printf("Unable to retrieve the firmware version!\r\n");
    version = 0;
  }
  else
  {
	printf_P(TextP);
    //printf("Firmware V. : ");
    printf("%d",major); 
	printf_P(TextX);
	//printf("."); 
	printf("%d",minor);
	printf_P(TextN);
    version = major; version <<= 8; version |= minor;
  }

  return version;
}

/**************************************************************************/
/*!
    @brief  Tries to read the 6-byte MAC address of the CC3100 module
*/
/**************************************************************************/
void displayMACAddress(void) {
  
  uint8_t macAddress[6];
  
  if(!cc3100.getMacAddress(macAddress))
  {
    printf_P(TextQ);
	//printf("Unable to retrieve MAC Address!\r\n");
  }
  else
  {
	printf_P(TextR);
    //printf("MAC Address : not printed but there\r\n");
    cc3100.printHex((byte*)&macAddress, 6);
  }
}



/**************************************************************************/
/*!
    @brief  Begins an SSID scan and prints out all the visible networks
*/
/**************************************************************************/

void listSSIDResults(void) {
 
  uint32_t index;
  uint8_t valid, rssi, sec,tuNumOfSSIDCnt;
  Sl_WlanNetworkEntry_t ssidname[20];
  char ptcSSIDBuff[50];

  if (!cc3100.startSSIDscan(&index)) {
	  printf_P(TextS);
	  //printf("SSID scan failed!\r\n");
	  return;
  }

  printf_P(TextT);
  //printf("Networks found: ");
  printf("%d",index);
  printf_P(TextN);
  //printf("\r\n");
  printf_P(TextU);
  //printf("================================================\r\n");
CLI_Write("SSID Scan FIKnished");
sprintf(ptcSSIDBuff,"Total SSID :- %d\r\n",index);
CLI_Write(ptcSSIDBuff);
CLI_Write("SSID Scanning finished\r\n");
cc3100.getNextSSIDList(0,index,ssidname);
CLI_Write("Here is a List :- ");

  //valid = cc3100.getNextSSIDList(rssi, sec,(Sl_WlanNetworkEntry_t*) ssidname); // TO DO Bhautik,update this function
  for(tuNumOfSSIDCnt = 0;tuNumOfSSIDCnt < index;tuNumOfSSIDCnt++)
  {
	  printf_P(TextV);
	  //printf("SSID Name: ");
	  printf("%s",ssidname[tuNumOfSSIDCnt].ssid);
	  printf_P(TextN);
	  CLI_Write(TextN);
	  //printf("\r\n");
	  CLI_Write("     ");
	  CLI_Write("(");
	  CLI_Write(tuNumOfSSIDCnt+1);
	  CLI_Write("). ");
	  sprintf(ptcSSIDBuff,"%s\r\n",ssidname[tuNumOfSSIDCnt].ssid);
	  CLI_Write(ptcSSIDBuff);
  }
  
  
  printf_P(TextU);
  //printf("================================================\r\n");
  cc3100.stopSSIDscan();

}



/**************************************************************************/
//    @brief  Set led color
/**************************************************************************/
void setColor(int red, int green, int blue) {

	//analogWrite(LED_PA0_R, red);
	//analogWrite(LED_PA2_G, green);
	//analogWrite(LED_PA1_B, blue);
	
}

void setUp32MhzInternalOsc() {
	
	OSC_CTRL |= OSC_RC32MEN_bm; //Setup 32Mhz crystal
	
	while(!(OSC_STATUS & OSC_RC32MRDY_bm));
	
	CCP = CCP_IOREG_gc; //Trigger protection mechanism
	CLK_CTRL = CLK_SCLKSEL_RC32M_gc; //Enable internal  32Mhz crystal
	
	
}


/**************************************************************************/
//    @brief  Function to clear a string
/**************************************************************************/
void clearStr (char* str) {
	
	int len = strlen(str);
	for (int c = 0; c < len; c++) {
		str[c] = 0;
	}
	
}

char* appendCharToCharArray(char* array, char a)
{
	size_t len = strlen(array);

	char *ret =(char*) malloc(len+2);

	strcpy(ret, array);
	ret[len] = a;
	ret[len+1] = '\0';

	return ret;
}





/**************************************************************************/
/*!
    @brief  Connect using save credentials
  */
  /**************************************************************************/
  bool configSavedCredentials(void) {
	  
	  //use stored credentials, when button is not pressed
	  // check for last config mode used

	  //char           ssid[30];
	  //char           pwd[30];
	  /* ======================== 2 ========================== */	  
	  if(gxCredentialInfo.uCredentialInfo == CREDENTIAL_PROCESS_SMARTCONFIG){
		  
			  
		  setColor(255, 0, 0);  // aqua
		  
		  if (!cc3100.begin(false, true, DEVICE_NAME))
		  {
			  setColor(0, 255, 255);  // red
			 nvm_eeprom_write_byte(EEPROM_CONFIGMODE_ADR, 0);
			 if(gxCredentialInfo.bIsCredentialSaved != true)
			 {
				 vProgressBAR(4,"Error ,Please Restart Device");
				 unregister_all_touch_objects();
			 }
			  return false;
			  //configSavedCredentials(); //try again
		  }
		
		  delay_ms(1500);
		  setColor(0, 0, 255);  // yellow
		  
		  
	  }
	  

	  /* ======================== 3 ========================== */
	  if (gxCredentialInfo.uCredentialInfo == CREDENTIAL_PROCESS_PROVISIONING_AP)
	  {
		  
		 if (!cc3100.begin(false, true, DEVICE_NAME))
		 {
			 nvm_eeprom_write_byte(EEPROM_CONFIGMODE_ADR, 0);
			 if(gxCredentialInfo.bIsCredentialSaved != true)
			 {
				 vProgressBAR(4,"Error ,Please Restart Device");
				 unregister_all_touch_objects();
			 }
			 return false;
		 }
		 delay_ms(1500);
		 return true;
		  
	  }

	  
  }
  

/**************************************************************************/
/*!
    @brief  Connect using TI Smart Config App
*/
/**************************************************************************/
bool configSmartConfig(void)
{
   
     if (!cc3100.begin(false))
      {
         setColor(0, 255, 255);  // red
		 unregister_all_touch_objects();
		 vProgressBAR(4,"Error ,Please Restart Device");
         return false;
		 //while(1);
      }
  
      displayMACAddress();
   
	    if (!cc3100.deleteProfiles()) {
                  // clearStr(row4buffer);
                  // snprintf (row4buffer,42, "%s%s", row4buffer, "Failed ..."); // to do bhautik,need to make snprintf
					//while(1);
					unregister_all_touch_objects();
					vProgressBAR(4,"Error ,Please Restart Device");
					return false;
      }
 
      vProgressBAR(1,"Click Start On Phone");
      if (!cc3100.startSmartConfig(DEVICE_NAME))
      {
 	   //printf_P(TextD1);
  	   setColor(0, 255, 255);  // red
 		 vProgressBAR(4,"Error ,Please Restart Device");
		 unregister_all_touch_objects();
		 return false;
      }
      setColor(0, 0, 255);  // yellow
 	  nvm_eeprom_write_byte(EEPROM_CONFIGMODE_ADR,CREDENTIAL_PROCESS_SMARTCONFIG);
      delay_ms(1000);
	  return true;
         
}

/**************************************************************************/
/*!
    @brief  Connect using input from USB serial terminal
*/
/**************************************************************************/
bool configProvisioningAP(void)
{
   int8_t index = 0;
   if (!cc3100.begin(false))
   {
	   setColor(0, 255, 255);  // red
	  vProgressBAR(4,"Error ,Please Restart Device");
	  unregister_all_touch_objects();
	  return false;
   }
   
   displayMACAddress();
   
   if (!cc3100.startProvisioningAP())
   {
	   CLI_Write("Provisioning AP Failed");
	   setColor(0, 255, 255);  // red
	   vProgressBAR(4,"Error ,Please Restart Device");
	   unregister_all_touch_objects();
	   return false;
   }
   else
   {
	   CLI_Write("Provisioning AP done");
   }
	
	// config mode provisioningAP(3)
   nvm_eeprom_write_byte(EEPROM_CONFIGMODE_ADR, CREDENTIAL_PROCESS_PROVISIONING_AP);
   
   //credentials saved - done.
   if(gxCredentialInfo.bIsCredentialSaved != true)
   {
	   vProgressBAR(1,"Credential Received");
	   vProgressBAR(2,"connecting to access point");
   }
   
   return true;    
  }

/**************************************************************************/
//    @brief  get configmode from NVM
/**************************************************************************/
uint8_t getConfigModeFromNVM(uint8_t NVMaddress){

return nvm_eeprom_read_byte(NVMaddress);
	
}
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
int main (void)
{
	setup();

	while (true)
	{
		if(bCredentialProcess())
		{
			vCredentialNetworkConnectProcess();
		}
		
		if(gxCredentialInfo.bCredentialProcessDone == true)
		{
			loop();
		}
		vFilterScreenDisplayCounting();
	}
}

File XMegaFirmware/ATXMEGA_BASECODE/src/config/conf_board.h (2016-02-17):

/**
 * \file
 *
 * \brief Board configuration
 *
 * Copyright (c) 2012 Atmel Corporation. All rights reserved.
 *
 * \asf_license_start
 *
 * \page License
 *
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
 * 3. The name of Atmel may not be used to endorse or promote products derived
 *    from this software without specific prior written permission.
 *
 * 4. This software may only be redistributed and used in connection with an
 *    Atmel microcontroller product.
 *
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
 * \asf_license_stop
 *
 */
#ifndef CONF_BOARD_H_INCLUDED
#define CONF_BOARD_H_INCLUDED

// Wifi
#define CC3100_nHIB_PIN			IOPORT_CREATE_PIN(PORTB, 2)
#define CC3100_RESET_PIN		IOPORT_CREATE_PIN(PORTB, 3)
#define CC3100_IRQ_PIN			IOPORT_CREATE_PIN(PORTD, 0)

#define CC3100_UART_TXD_PIN		IOPORT_CREATE_PIN(PORTF, 3)
#define CC3100_UART_RXD_PIN		IOPORT_CREATE_PIN(PORTF, 2)

#define CC3100_SPI				&SPIC
#define CC3100_SPI_SS_PIN		IOPORT_CREATE_PIN(PORTC, 4)
#define CC3100_SPI_MOSI_PIN		IOPORT_CREATE_PIN(PORTC, 5)
#define CC3100_SPI_MISO_PIN		IOPORT_CREATE_PIN(PORTC, 6)
#define CC3100_SPI_SCK_PIN		IOPORT_CREATE_PIN(PORTC, 7)

// Display
#define TFT_DISPLAY_USART_SPI      &USARTC0 //usartc1
#define TFT_DISPLAY_CS             IOPORT_CREATE_PIN(PORTB, 0) //PC 4
#define TFT_DISPLAY_SCK            IOPORT_CREATE_PIN(PORTC, 1) //7
#define TFT_DISPLAY_MOSI           IOPORT_CREATE_PIN(PORTC, 3) //5
#define TFT_DISPLAY_MISO           IOPORT_CREATE_PIN(PORTC, 2) //6
#define TFT_DISPLAY_CHG            IOPORT_CREATE_PIN(PORTC, 2)
#define TFT_DISPLAY_DC             IOPORT_CREATE_PIN(PORTB, 1) //PC 3
#define TFT_DISPLAY_BACKLIGHT      IOPORT_CREATE_PIN(PORTA, 4)
#define TFT_DISPLAY_LCD_RESET      IOPORT_CREATE_PIN(PORTA, 6)

// Touch
#define TOUCH_SPI                     &USARTE0
#define TOUCH_CS                      IOPORT_CREATE_PIN(PORTE, 0)
#define TOUCH_MASTER_SCK              IOPORT_CREATE_PIN(PORTE, 1)
#define TOUCH_MASTER_MOSI             IOPORT_CREATE_PIN(PORTE, 3)
#define TOUCH_MASTER_MISO             IOPORT_CREATE_PIN(PORTE, 2)
#define TOUCH_INT                     IOPORT_CREATE_PIN(PORTC, 0)
#define TOUCH_INTC_INIT()           ioport_configure_pin(TOUCH_INT, IOPORT_DIR_INPUT); \
									PORTC.PIN0CTRL = PORT_ISC0_bm; \
									PORTC.INT0MASK = PIN0_bm; \
									PORTC.INTFLAGS = PORT_INT0IF_bm;
									
//! \name DataFlash memory (AT45DBX)

#define AT45DBX_SPI                     &USARTD0
#define AT45DBX_CS                      IOPORT_CREATE_PIN(PORTF, 4)
#define AT45DBX_MASTER_SCK              IOPORT_CREATE_PIN(PORTD, 1)
#define AT45DBX_MASTER_MOSI             IOPORT_CREATE_PIN(PORTD, 3)
#define AT45DBX_MASTER_MISO             IOPORT_CREATE_PIN(PORTD, 2)

// Necessary After adding tft
/** Enables the transceiver main interrupt. */
#define ENABLE_TRX_IRQ()                (PORTC.INTCTRL |= PORT_INT0LVL_gm)

/** Disables the transceiver main interrupt. */
#define DISABLE_TRX_IRQ()               (PORTC.INTCTRL &= ~PORT_INT0LVL_gm)

/** Clears the transceiver main interrupt. */
#define CLEAR_TRX_IRQ()                 (PORTC.INTFLAGS = PORT_INT0IF_bm)

/* Enable the TFT Display */
#define CONF_BOARD_ENABLE_TFT_DISPLAY

// Enable AT45DBX Component.
#define CONF_BOARD_AT45DBX

// SRAM Pin Conf
#define SRAM23Kxx_SPI           CC3100_SPI
#define SRAM23Kxx_CS			IOPORT_CREATE_PIN(PORTA, 5)
#define SRAM23Kxx_SCK			CC3100_SPI_SCK_PIN
#define SRAM23Kxx_MOSI			CC3100_SPI_MOSI_PIN
#define SRAM23Kxx_MISO			CC3100_SPI_MISO_PIN
#define CONF_SRAM23Kxx_CLOCK_SPEED 8000000

//#define BOARD_XOSC_HZ          8000000
//#define BOARD_XOSC_TYPE        XOSC_TYPE_XTAL
//#define BOARD_XOSC_STARTUP_US  500000


#endif /* CONF_BOARD_H_INCLUDED */
